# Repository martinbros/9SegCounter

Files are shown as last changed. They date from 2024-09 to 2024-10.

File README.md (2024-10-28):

# Nine Segment Counter SAO

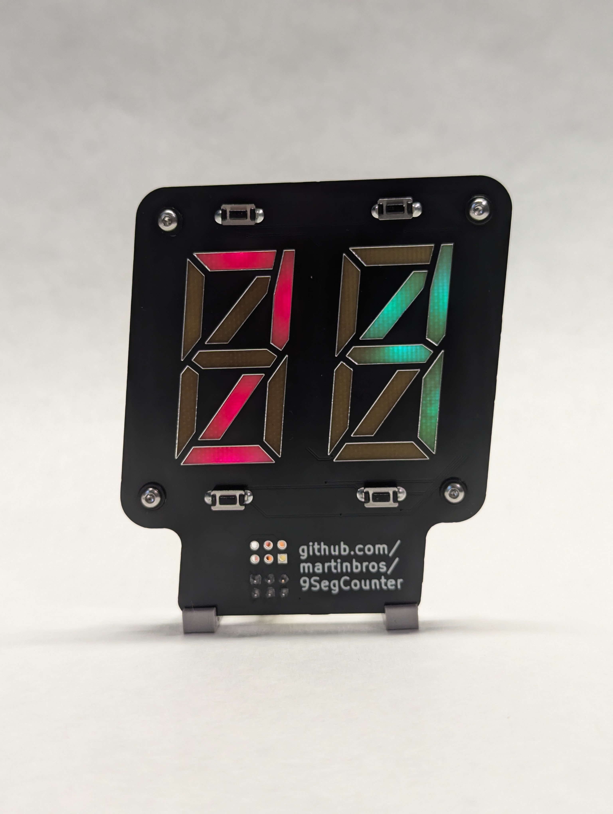
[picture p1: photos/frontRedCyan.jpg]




**Description**

Use this handy little SAO to count whatever your heart desires: how many conversations you have at Supercon, how many times someone asks what SAO stands for, how many times someone asks "What are you working on?".
By using the onboard buttons, I2C interface, or clocking the GP2 pin, the Nine Segment Counter SAO will indicate to the world whatever quantity you are keeping track of.

## Operation

Store a 2 digit number and display the number using an atypical 9 segment display instead of the typical 7

Using the buttons, a user can store 49 unique numbers in non-volatile memory. Each unique number is identified by the color of the digits.

Using the I2C bus, the user has full read and write access to the ATTiny 84's 512 byte EEPROM and has full command of the display (displayed number and digit color).

### Button Interface

- Pressing a button above a digit increases that digit by 1
- Pressing a button below a digit decreases that digit by 1
- The displayed digit is stored as a decimal 2 digit number (0-99)
- Pressing the buttons above and below a digit simultaneously changes the color of that digit
  - Each unique two digit color combination corresponds to a unique number saved in non-volatile memory
  - 7 unique colors per "ones" digit x 7 unique colors per "tens" digit = 49 unique values stored in non-volatile memory
  - EEPROM Address location is built by taking the "ones" position color index (0-6) and adding it to the "tens" position color index which has been multipled by 10 (0-6 x 10) [e.g. 00, 02, 03 ... 07, 10, 11 ... 17, 20 ... 27 ... 77]

### I2C Interface

- I2C Address: 4

**Display Functions**

- 1 8-bit message: the display will update to show the sent number (Displayed number is not stored in memory)
- 3 8-bit messages: set the RGB values of the digits to be displayed (Digit must be refreshed to update color)
- 6 8-bit messages: set the RGB values of the tens place digit and then ones place digit (Digit must be refreshed to update color)

**Memory Functions**

- 2 8-bit message: The sent number is converted to a 16-bit EEPROM address pointer, the display will update to display the value stored in memory.
- 4 8-bit messages: first 2 bytes are combined to a 16-bit EEPROM address pointer, third byte is the data to be stored in the EEPROM, the last byte is a throwaway
- 5 8-bit messages: The entire EEPROM is filled with the contents of the first message, the remaining 4 messages are discarded

### GP1 Interface

- GP1 is normally pulled high. By driving GP1 low, the displayed number will be incremented by 1
- Max clock speed is ~150Hz
- Displayed number is not stored in memory 

### GP2 Interface

- GP2 is connected directly to the first Neopixel and is terminated with a 470 ohm resistor. If you desire, feel free to implement the Neopixel protocol and set the segments however you like! Use the reference photo below for the sequence of the neopixels.

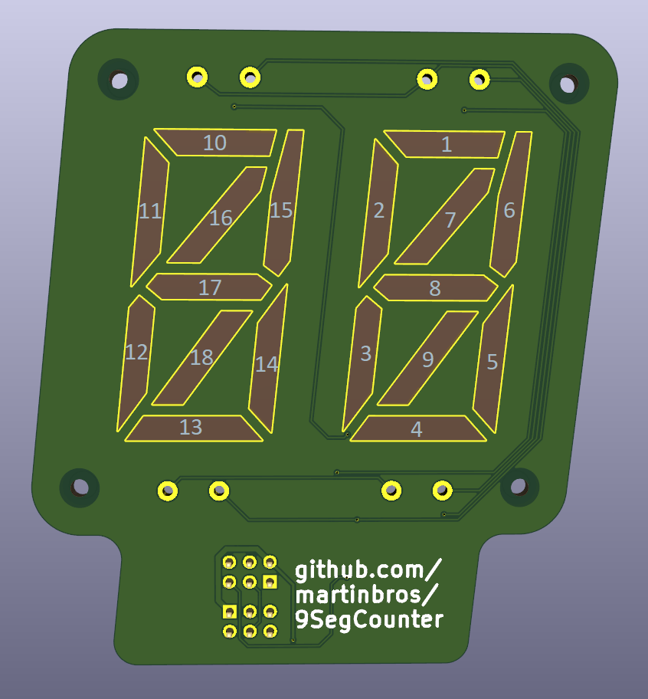
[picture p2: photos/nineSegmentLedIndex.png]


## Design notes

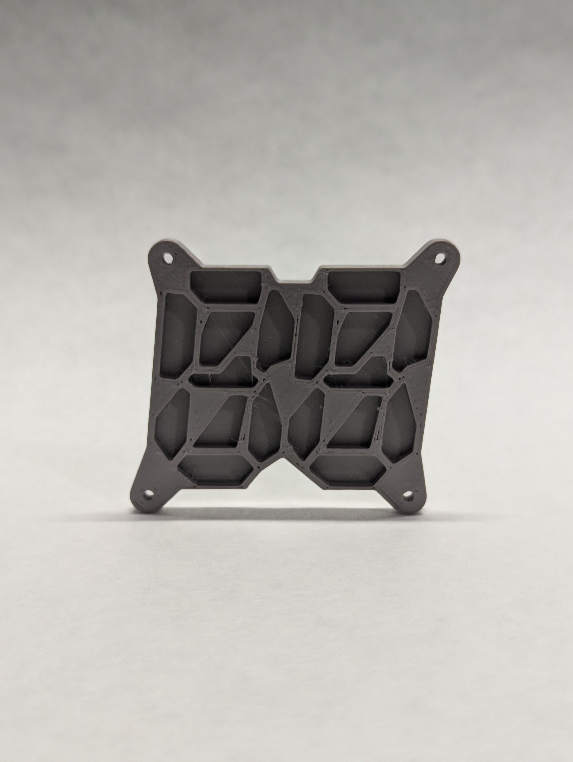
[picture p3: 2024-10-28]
photos/separator.jpg

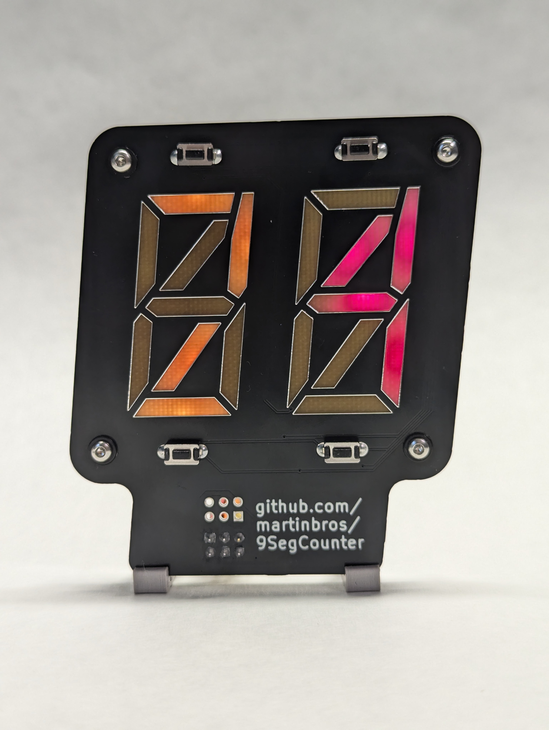
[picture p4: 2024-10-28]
photos/frontYellowRed.jpg

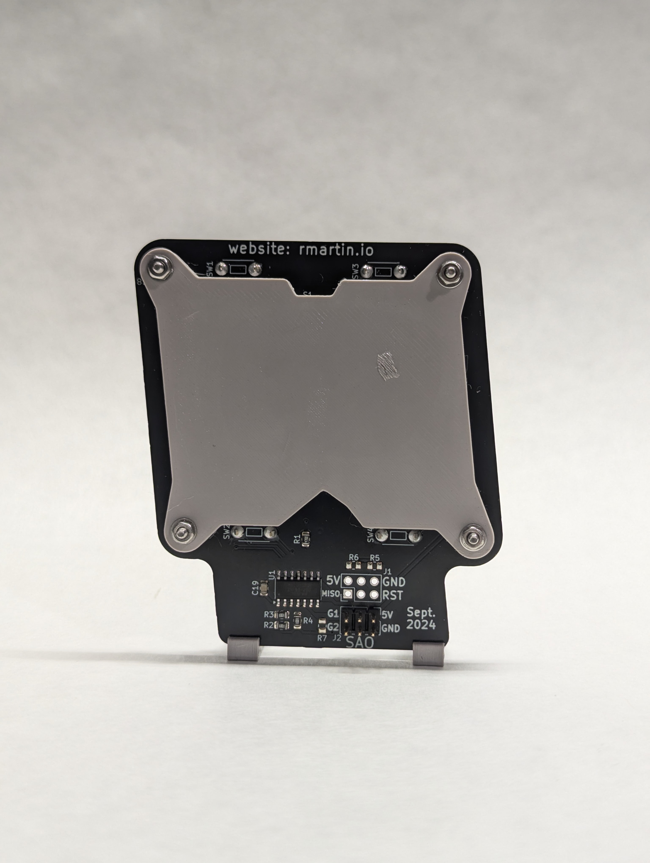
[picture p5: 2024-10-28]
photos/backSeparator.jpg

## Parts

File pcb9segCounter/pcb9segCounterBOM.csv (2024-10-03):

Reference | Value | Datasheet | Footprint | Qty | DNP | MFG | MPN
C1,C2,C3,C4,C5,C6,C7,C8,C9,C10,C11,C12,C13,C14,C15,C16,C17,C18,C19 | 0.1u | ~ | Capacitor_SMD:C_0805_2012Metric | 19 |  | Kemet | C0805C104K5RAC7210
D1,D2,D3,D4,D5,D6,D7,D8,D9,D10,D11,D12,D13,D14,D15,D16,D17,D18 | ~ | https://cdn-shop.adafruit.com/product-files/5849/SK6805-EC10-000_REV.01_EN.pdf | customParts:1x1mm SMD RGB LED | 18 |  | Dongguan | SK6805-EC10
J1 | AVR-ISP-6 | ~ | Connector_PinHeader_2.54mm:PinHeader_2x03_P2.54mm_Vertical | 1 |  | Amphenol FCI | 10129381-906002BLF
J2 | SAO | ~ | Connector_PinHeader_2.54mm:PinHeader_2x03_P2.54mm_Vertical | 1 |  | Amphenol FCI | 10129381-906002BLF
R1 | 500 | ~ | Resistor_SMD:R_0805_2012Metric | 1 |  | Yago | RC0805FR-07470RL
R2,R3,R5,R6,R7 | 1k | ~ | Resistor_SMD:R_0805_2012Metric | 5 |  | Yago | RC0805FR-071KL
R4 | 1k | ~ | Resistor_SMD:R_0805_2012Metric_Pad1.20x1.40mm_HandSolder | 1 |  | Yago | RC0805FR-071KL
S1,S2 | ~ |  | customParts:9 Segment 38x19x3 | 2 |  | na | na
SW1,SW2,SW3,SW4 | ~ | ~ | customParts:PTS636 SK43 LFS | 4 |  | C&K | PTS636 SK43 LFS
U1 | ATtiny84A-SS | http://ww1.microchip.com/downloads/en/DeviceDoc/doc8183.pdf | Package_SO:SOIC-14_3.9x8.7mm_P1.27mm | 1 |  | Microchip | ATTINY84-20SSU

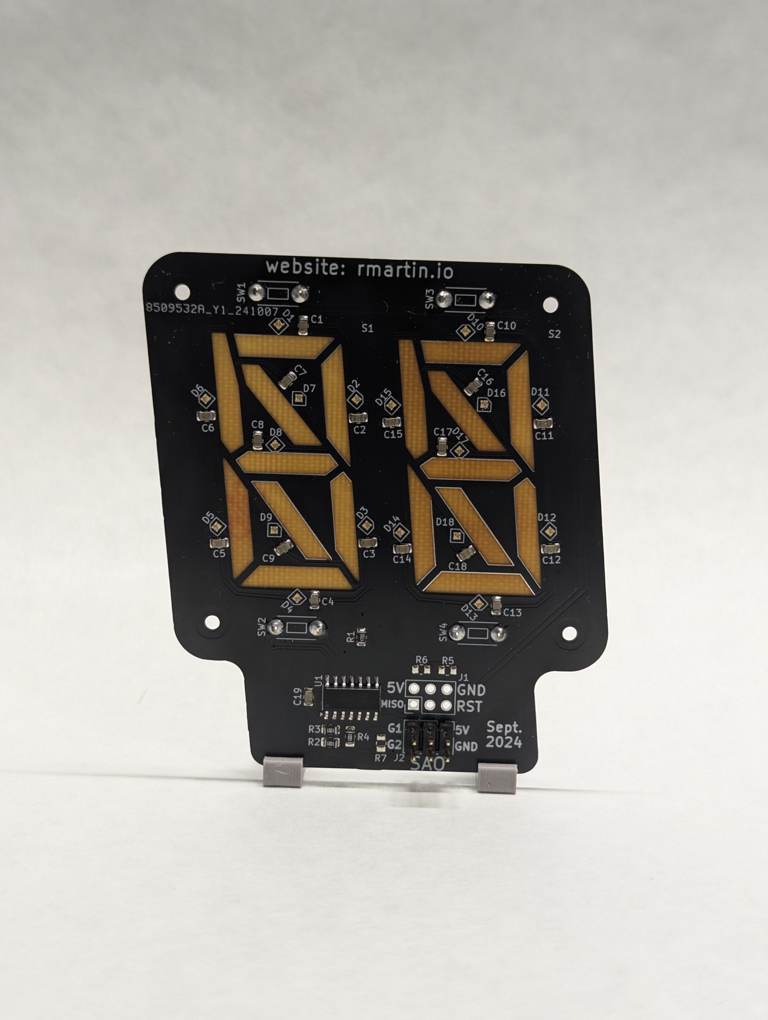
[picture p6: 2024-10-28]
photos/backComponents.jpg

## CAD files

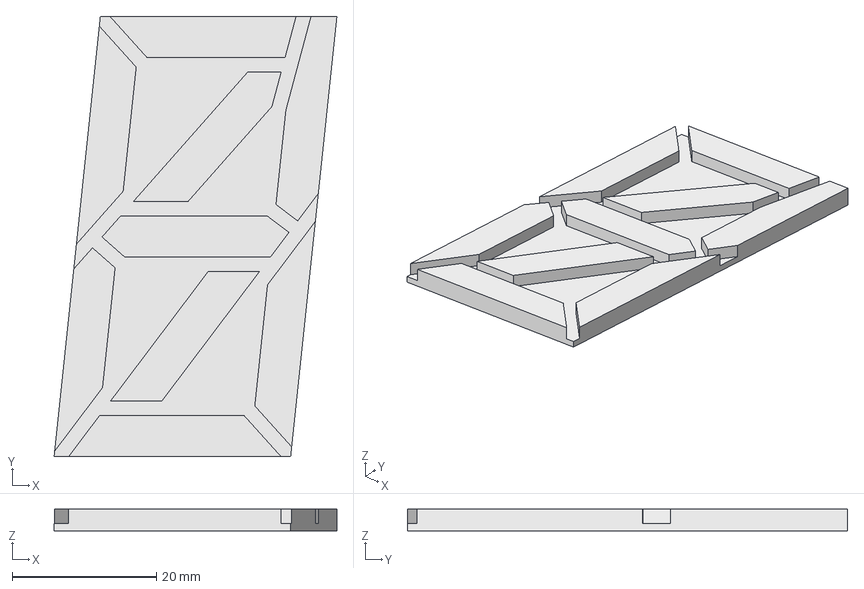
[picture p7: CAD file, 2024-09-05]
cad9segment/9SegmentV2.FCStd
39.2 x 61.0 x 3.00 mm

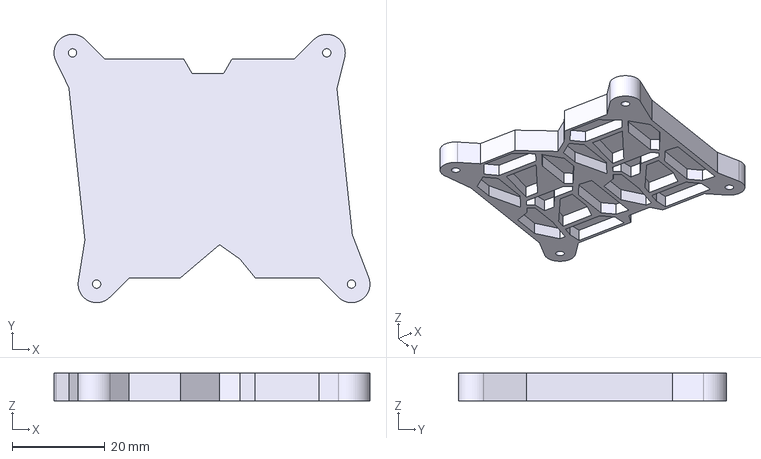
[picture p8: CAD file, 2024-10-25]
cadBackSeparator/saoBackSeparator-TaperedHoles.step
68.2 x 57.9 x 6.00 mm

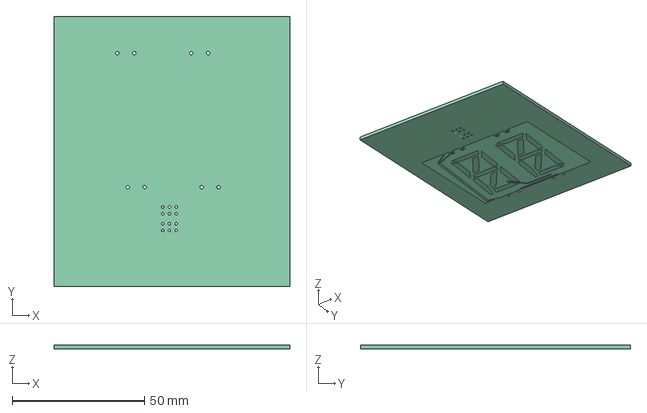
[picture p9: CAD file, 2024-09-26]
pcb9segCounter/3dModelOfBoard/3dBoard.FCStd
89.2 x 102.2 x 1.61 mm
Pcb_a7f9
botZones_a7f9

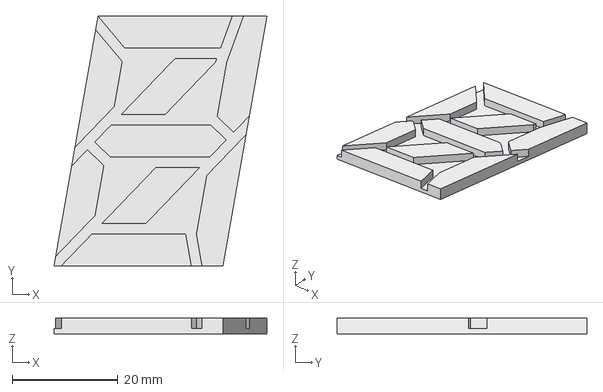
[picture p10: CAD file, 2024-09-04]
cad9segment/9segmentDisplay.FCStd
40.3 x 47.3 x 3.00 mm

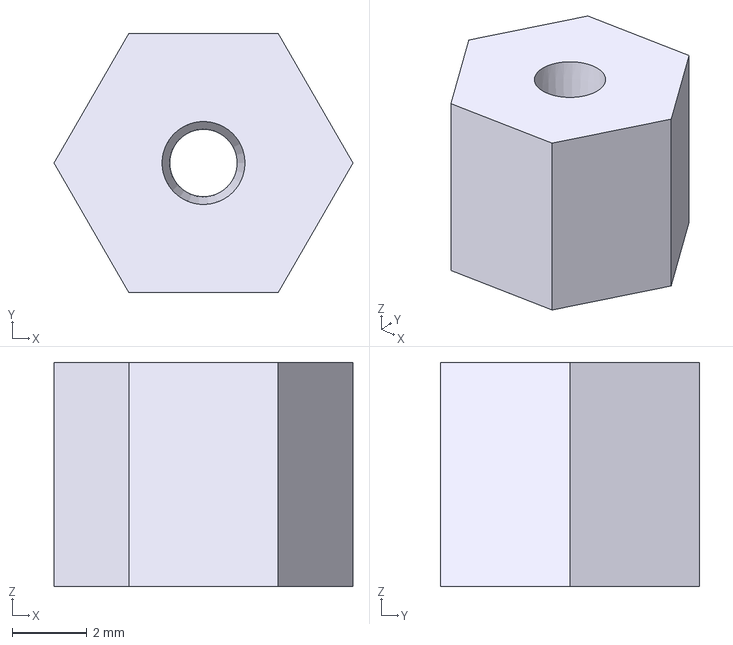
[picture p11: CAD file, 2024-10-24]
cadBackSeparator/saoBackSeparator.FCStd
8.00 x 6.93 x 6.00 mm

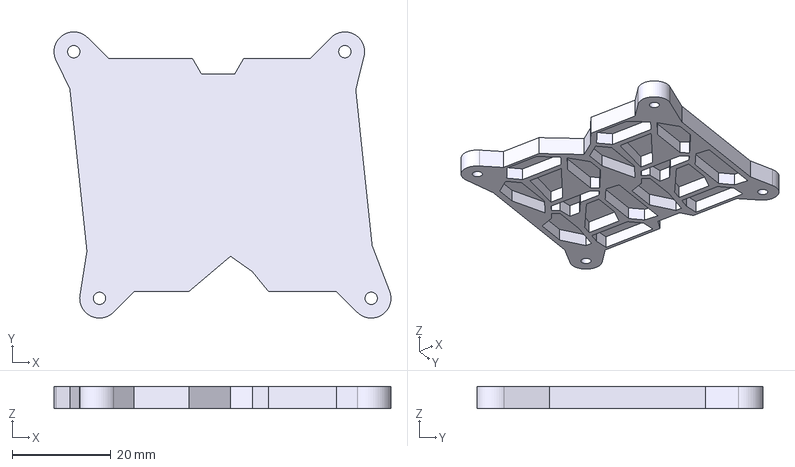
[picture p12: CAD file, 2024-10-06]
cadBackSeparator/saoBackSeparator-rightHoles.step
68.2 x 57.9 x 4.50 mm

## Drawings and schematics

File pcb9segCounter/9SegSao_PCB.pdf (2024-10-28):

1 | 2 | 3 | 4 | 5 | 6

A

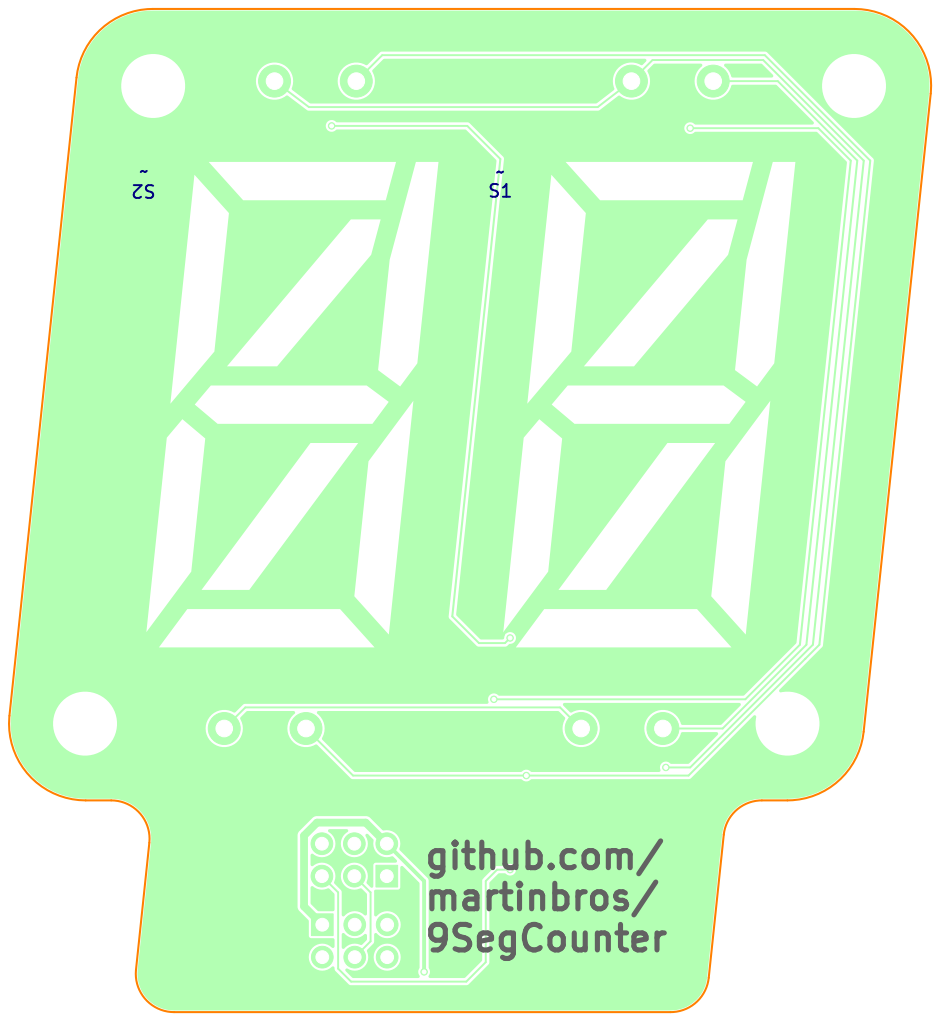
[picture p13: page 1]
github.com/ martinbros/ 9SegCounter; D Date: KiCad; E.D.A. 8.0.5 Size: A4; Rev:

Id: 1/1 Title: File: pcb9segCounter.kicad_pcb Sheet:

# Sept. 2024 website: rmartin.io

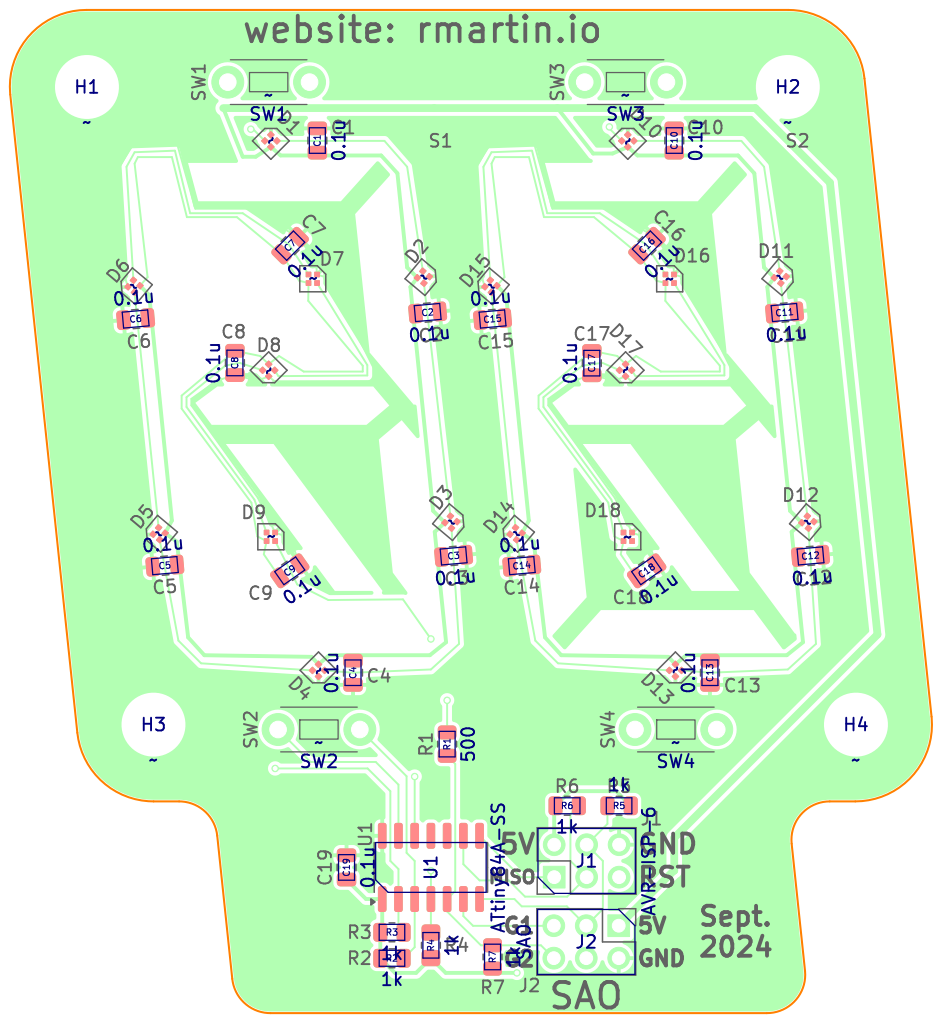
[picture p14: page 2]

# Sept. 2024 website: rmartin.io

A

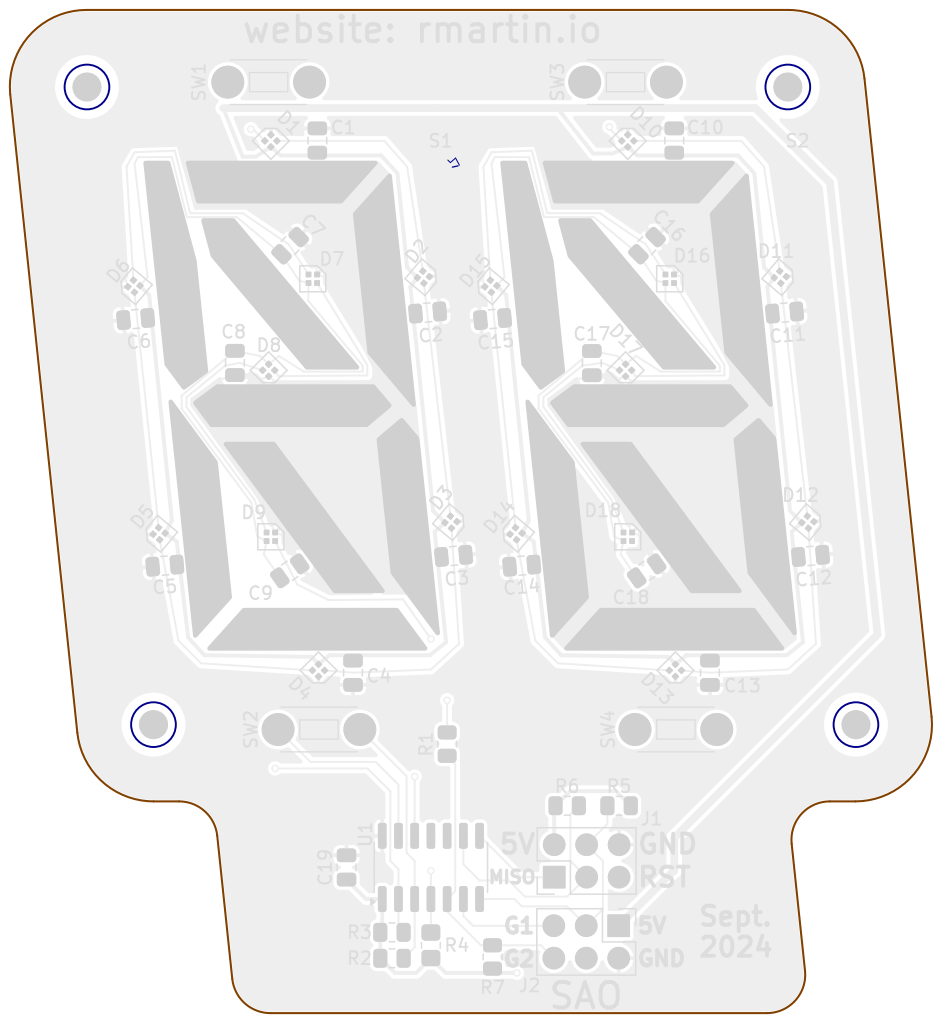
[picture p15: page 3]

Id: 1/1 Title: File: pcb9segCounter.kicad_pcb Sheet:

A

A

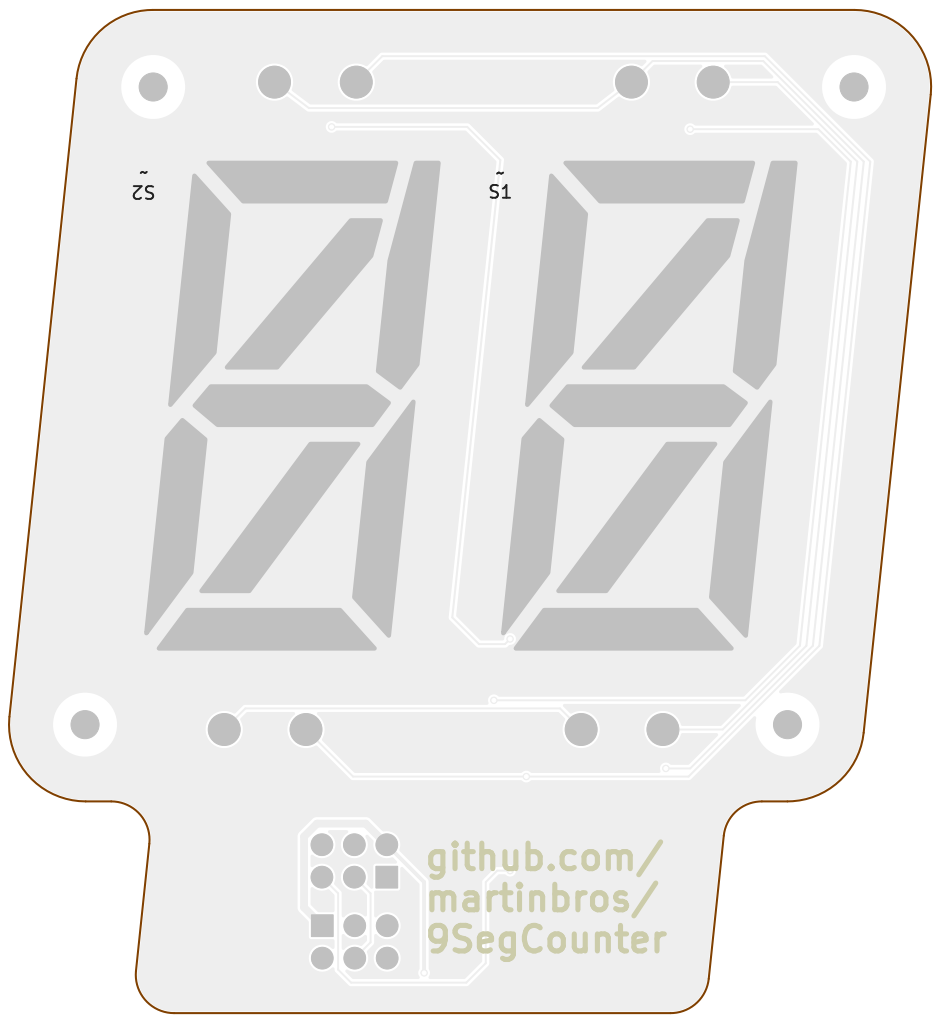
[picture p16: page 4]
github.com/ martinbros/ 9SegCounter; D Date: KiCad; E.D.A. 8.0.5 Size: A4; Rev:

Id: 1/1 Title: File: pcb9segCounter.kicad_pcb Sheet:

# Sept. 2024 website: rmartin.io

R3 0.1u | C⁴ ~H1 | 0.1u C¹⁹ | 1kR⁷ ~ | ~ ATtiny84A⁻SS U¹ | 500R¹ | ~H4 ⁰.1uC¹ ~ SW1 | 1kR⁴ ~ | 0.1u | C¹⁷ 1 | 2 | 3 | 4 | 5 | 6 1 | 2 | 3 | 4 | 5 | 6 ABCD | ABCD Date: KiCad | E.D.A. 8.0.5 Size: A4 | Rev:

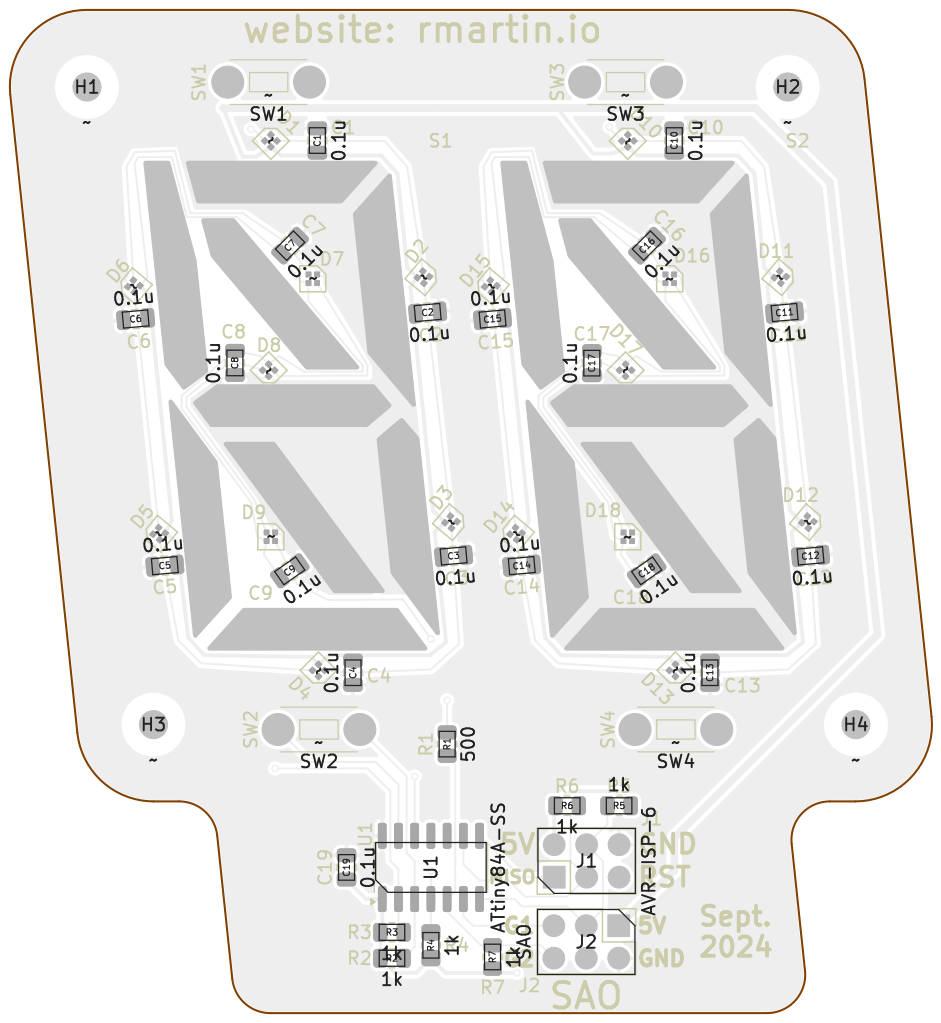
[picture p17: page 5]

Id: 1/1 Title: File: pcb9segCounter.kicad_pcb Sheet:

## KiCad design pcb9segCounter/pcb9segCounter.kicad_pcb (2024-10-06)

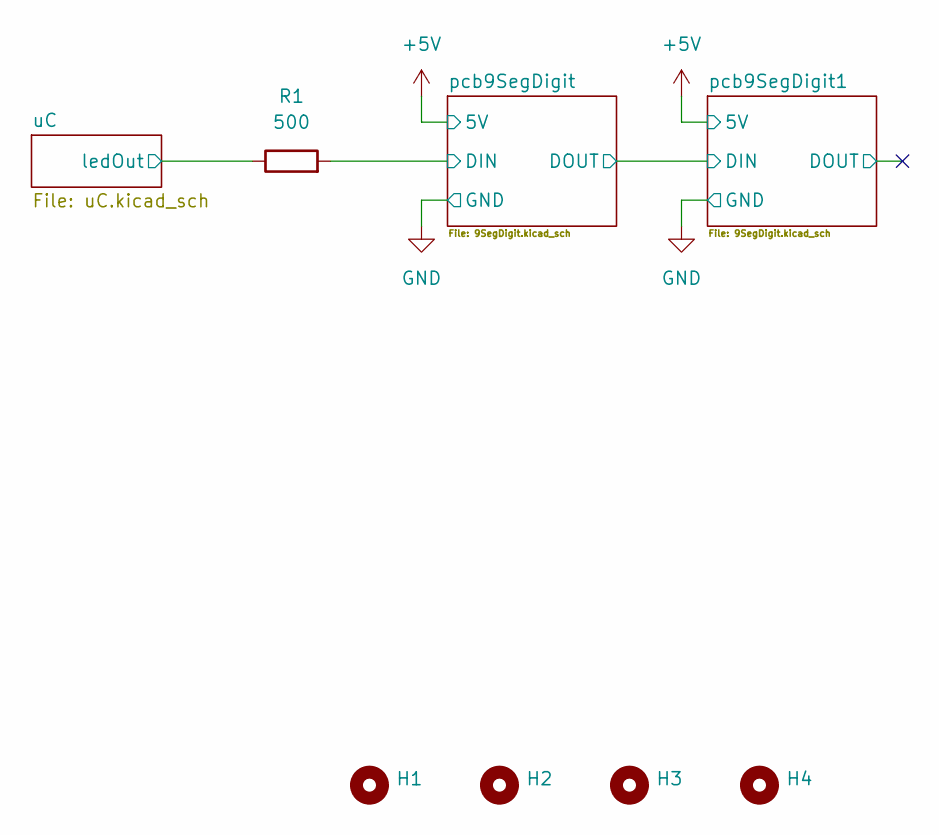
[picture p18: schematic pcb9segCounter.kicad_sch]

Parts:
H1, H2, H3, H4: MountingHole_2.2mm_M2_ISO7380
R1: 500; R_0805_2012Metric

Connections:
/pcb9SegDigit/DIN: R1.2; also elsewhere on the board
GP2: R1.1; also elsewhere on the board

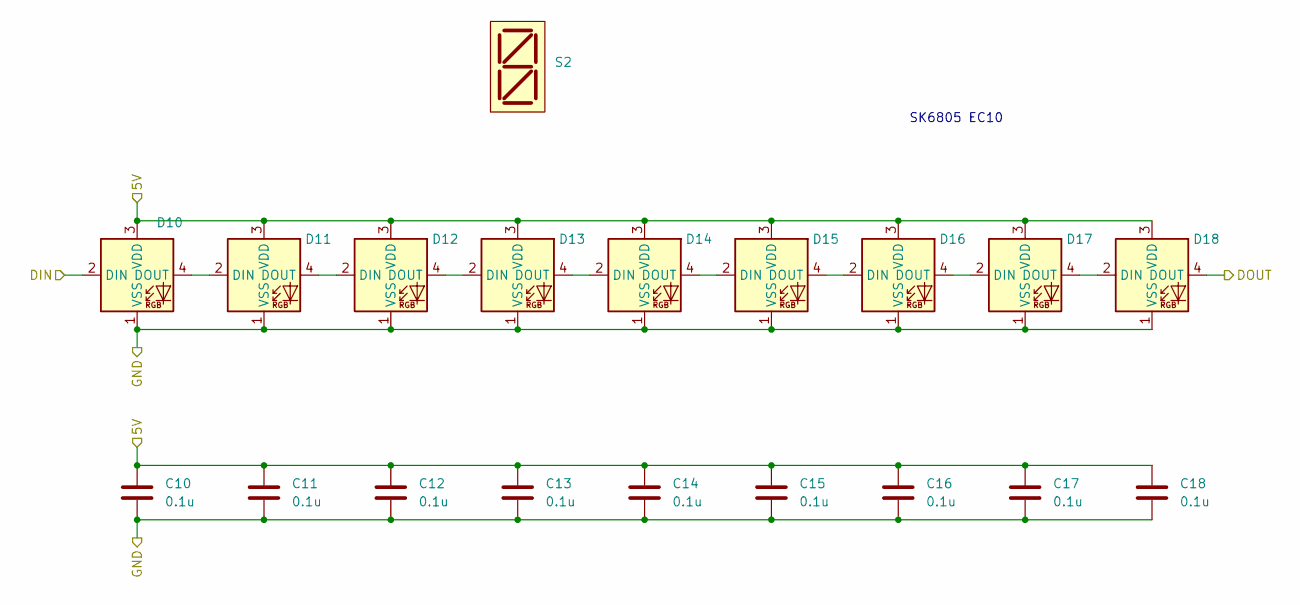
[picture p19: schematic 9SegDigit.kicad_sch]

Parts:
C10, C11, C12, C13, C14, C15, C16, C17, C18: 0.1u; C_0805_2012Metric
D10, D11, D12, D13, D14, D15, D16, D17, D18: 1x1mm SMD RGB LED; MPN SK6805-EC10
S2: 9 Segment 38x19x3

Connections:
+5V: C10.1, C11.1, C12.1, C13.1, C14.1, C15.1, C16.1, C17.1, C18.1, D10.3 (VDD), D11.3 (VDD), D12.3 (VDD), D13.3 (VDD), D14.3 (VDD), D15.3 (VDD), D16.3 (VDD), D17.3 (VDD), D18.3 (VDD); also elsewhere on the board
/pcb9SegDigit1/DOUT: D18.4 (DOUT)
/pcb9SegDigit/DOUT: D10.2 (DIN); also elsewhere on the board
GND: C10.2, C11.2, C12.2, C13.2, C14.2, C15.2, C16.2, C17.2, C18.2, D10.1 (VSS), D11.1 (VSS), D12.1 (VSS), D13.1 (VSS), D14.1 (VSS), D15.1 (VSS), D16.1 (VSS), D17.1 (VSS), D18.1 (VSS); also elsewhere on the board
unnamed: D10.4 (DOUT), D11.2 (DIN)
unnamed: D11.4 (DOUT), D12.2 (DIN)
unnamed: D12.4 (DOUT), D13.2 (DIN)
unnamed: D13.4 (DOUT), D14.2 (DIN)
unnamed: D14.4 (DOUT), D15.2 (DIN)
unnamed: D15.4 (DOUT), D16.2 (DIN)
unnamed: D16.4 (DOUT), D17.2 (DIN)
unnamed: D17.4 (DOUT), D18.2 (DIN)

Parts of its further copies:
C1, C2, C3, C4, C5, C6, C7, C8, C9: 0.1u; C_0805_2012Metric
D1, D2, D3, D4, D5, D6, D7, D8, D9: 1x1mm SMD RGB LED; MPN SK6805-EC10
S1: 9 Segment 38x19x3

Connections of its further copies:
+5V: C1.1, C2.1, C3.1, C4.1, C5.1, C6.1, C7.1, C8.1, C9.1, D1.3 (VDD), D2.3 (VDD), D3.3 (VDD), D4.3 (VDD), D5.3 (VDD), D6.3 (VDD), D7.3 (VDD), D8.3 (VDD), D9.3 (VDD); also elsewhere on the board
/pcb9SegDigit/DIN: D1.2 (DIN); also elsewhere on the board
/pcb9SegDigit/DOUT: D9.4 (DOUT); also elsewhere on the board
GND: C1.2, C2.2, C3.2, C4.2, C5.2, C6.2, C7.2, C8.2, C9.2, D1.1 (VSS), D2.1 (VSS), D3.1 (VSS), D4.1 (VSS), D5.1 (VSS), D6.1 (VSS), D7.1 (VSS), D8.1 (VSS), D9.1 (VSS); also elsewhere on the board
unnamed: D1.4 (DOUT), D2.2 (DIN)
unnamed: D2.4 (DOUT), D3.2 (DIN)
unnamed: D3.4 (DOUT), D4.2 (DIN)
unnamed: D4.4 (DOUT), D5.2 (DIN)
unnamed: D5.4 (DOUT), D6.2 (DIN)
unnamed: D6.4 (DOUT), D7.2 (DIN)
unnamed: D7.4 (DOUT), D8.2 (DIN)
unnamed: D8.4 (DOUT), D9.2 (DIN)

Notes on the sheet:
SK6805 EC10

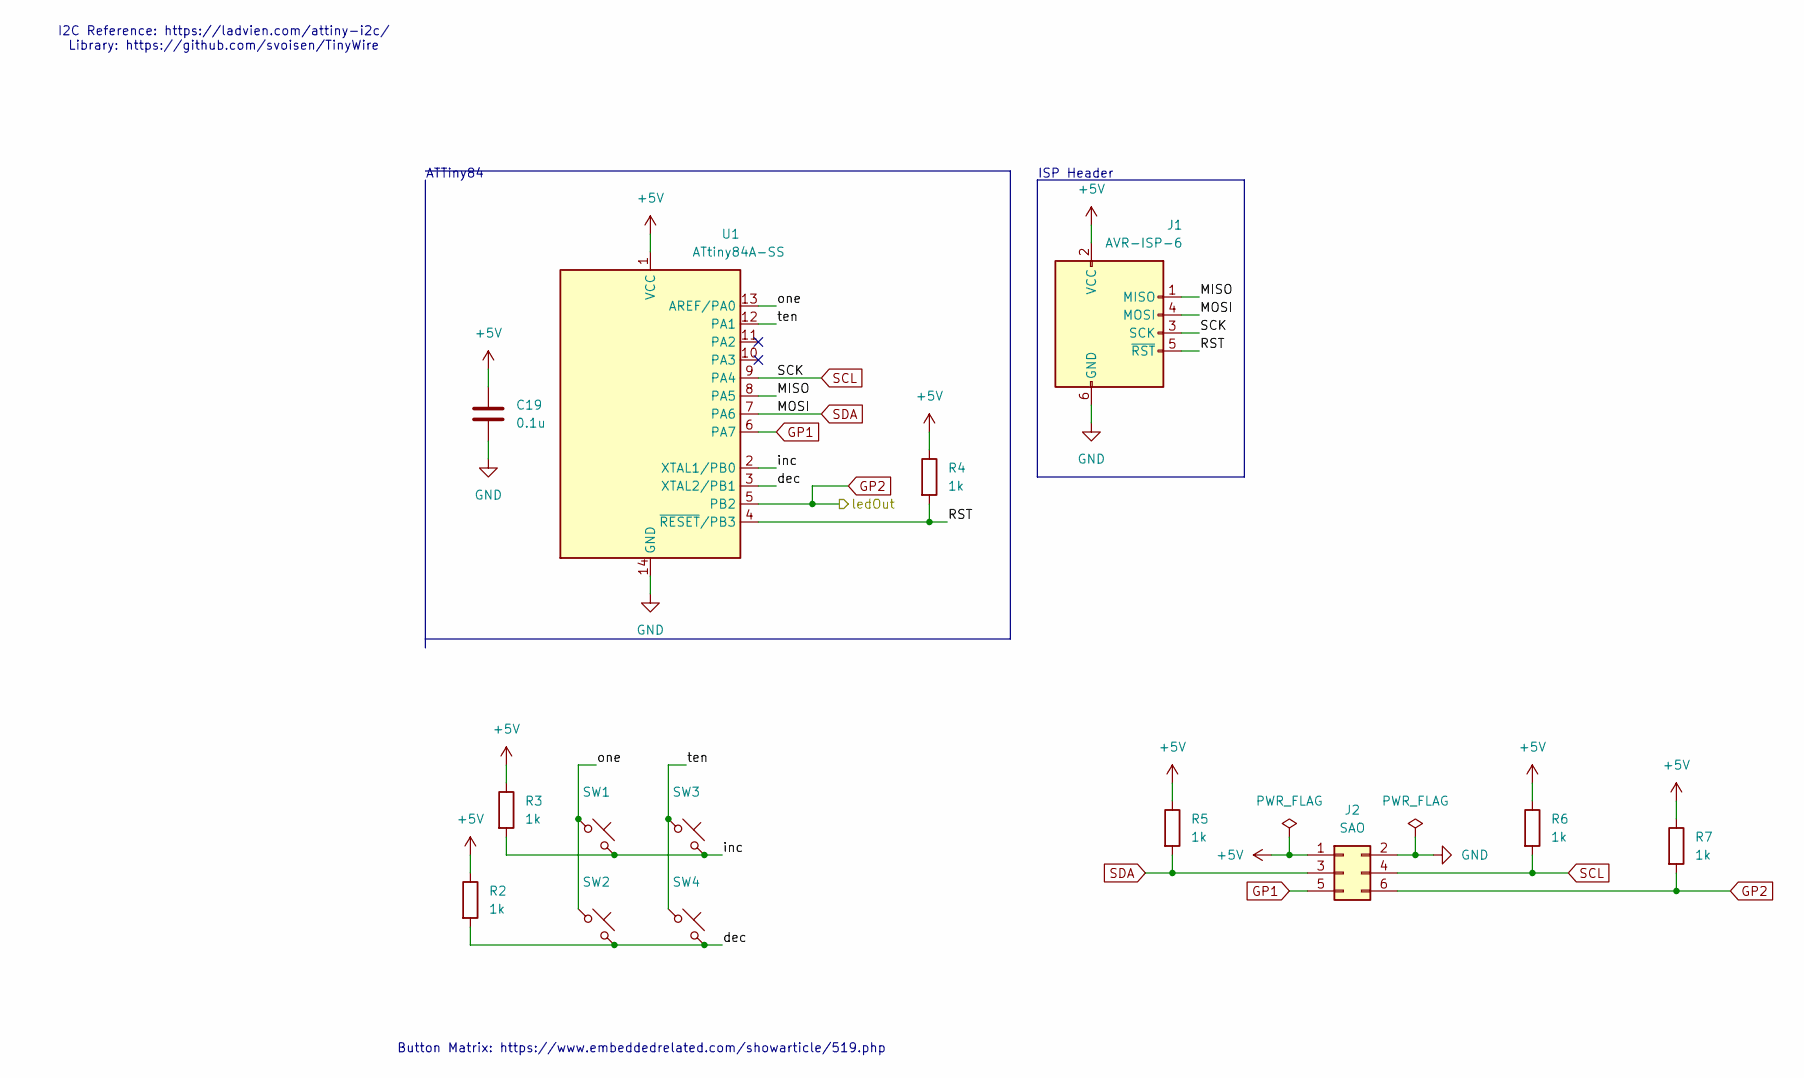
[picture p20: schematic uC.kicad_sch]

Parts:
C19: 0.1u; C_0805_2012Metric; mouserPN 80-C0805C104M3R
J1: AVR-ISP-6; PinHeader_2x03_P2.54mm_Vertical; MPN 10129381-906002BLF
J2: SAO; PinHeader_2x03_P2.54mm_Vertical; MPN 10129381-906002BLF
R2, R3, R5, R6, R7: 1k; R_0805_2012Metric
R4: 1k; R_0805_2012Metric_Pad1.20x1.40mm_HandSolder; mouserPN 71-CRCW08051K00JNEAC
SW1, SW2, SW3, SW4: PTS636 SK43 LFS; MPN PTS636 SK43 LFS
U1: ATtiny84A-SS; SOIC-14_3.9x8.7mm_P1.27mm; mouserPN 556-ATTINY84-20SSU

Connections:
+5V: C19.1, J1.2 (VCC), J2.1, R2.1, R3.1, R4.1, R5.1, R6.1, R7.1, U1.1 (VCC); also elsewhere on the board
/uC/MISO: J1.1 (MISO), U1.8 (PA5)
/uC/RST: J1.5 (~RST), R4.2, U1.4 (~RESET/PB3)
/uC/dec: R2.2, SW2.2, SW4.2, U1.3 (XTAL2/PB1)
/uC/inc: R3.2, SW1.2, SW3.2, U1.2 (XTAL1/PB0)
/uC/one: SW1.1, SW2.1, U1.13 (AREF/PA0)
/uC/ten: SW3.1, SW4.1, U1.12 (PA1)
GND: C19.2, J1.6 (GND), J2.2, U1.14 (GND); also elsewhere on the board
GP1: J2.5, U1.6 (PA7)
GP2: J2.6, R7.2, U1.5 (PB2); also elsewhere on the board
SCL: J1.3 (SCK), J2.4, R6.2, U1.9 (PA4)
SDA: J1.4 (MOSI), J2.3, R5.2, U1.7 (PA6)

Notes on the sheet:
ATTiny84
ISP Header
I2C Reference: https://ladvien.com/attiny-i2c/ Library: https://github.com/svoisen/TinyWire
Button Matrix: https://www.embeddedrelated.com/showarticle/519.php

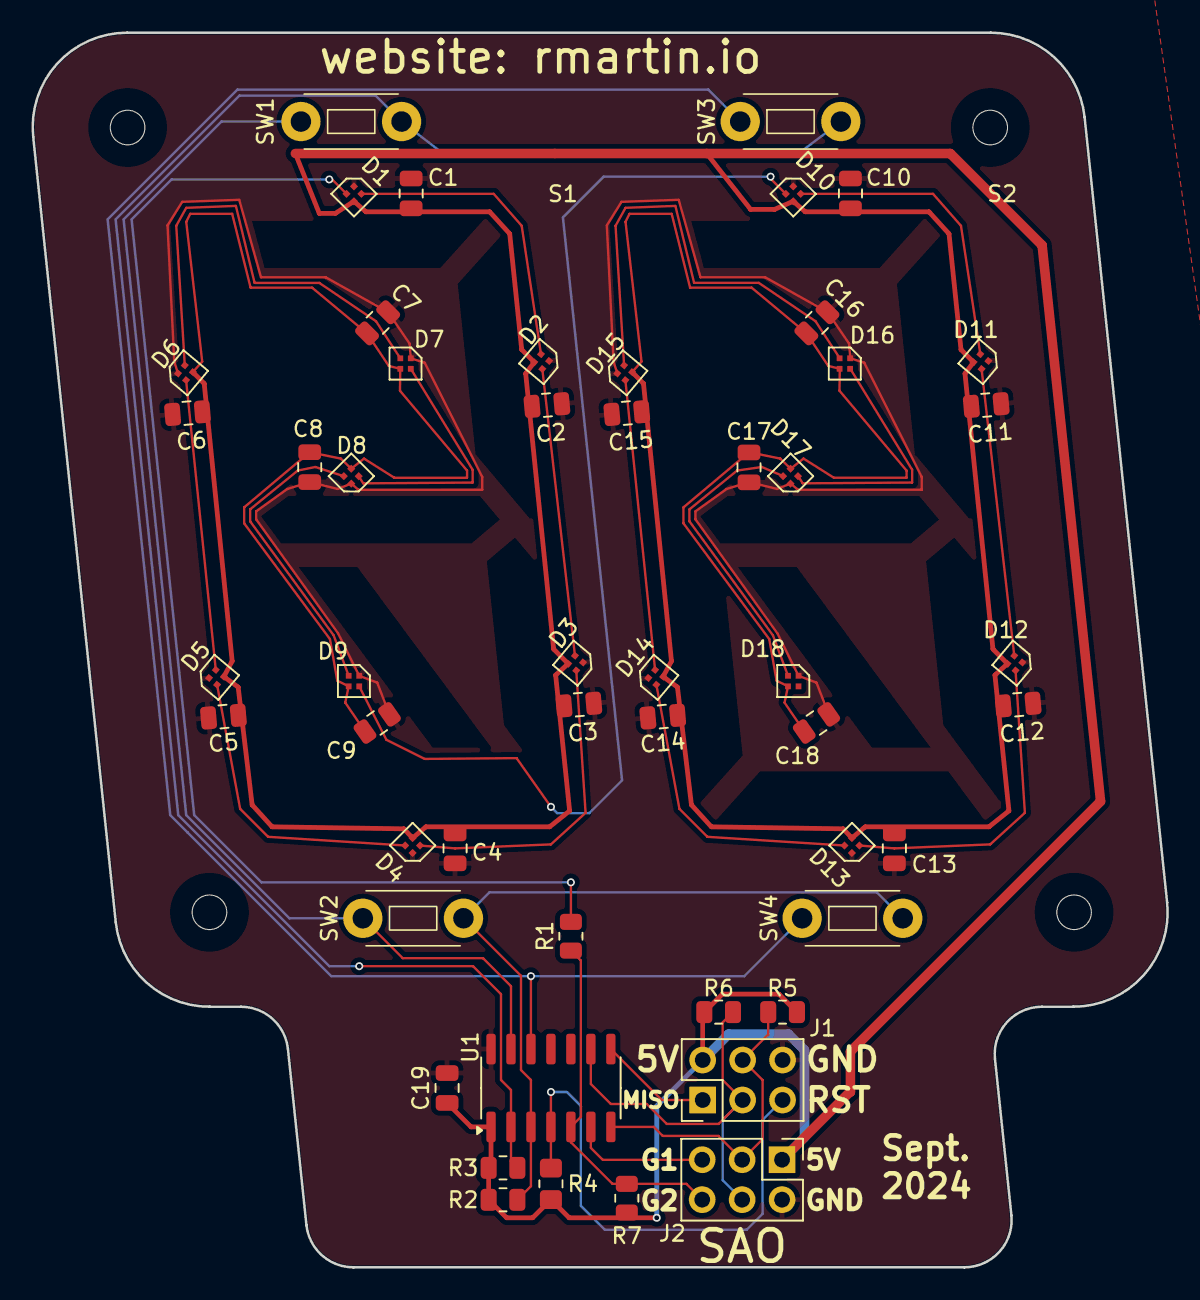
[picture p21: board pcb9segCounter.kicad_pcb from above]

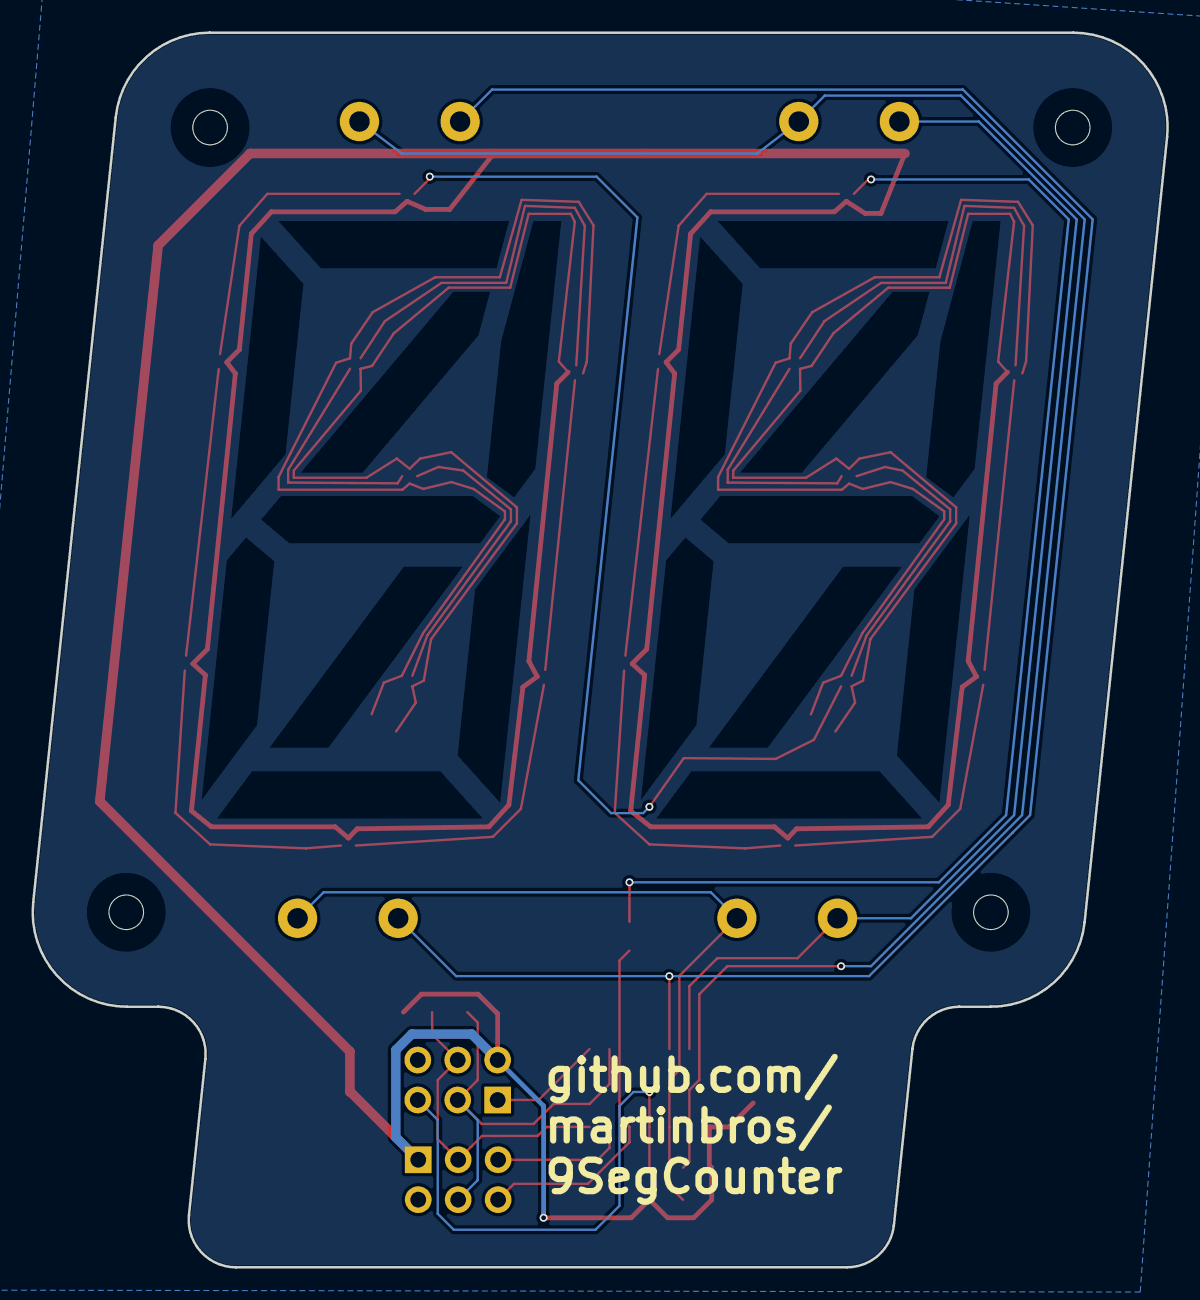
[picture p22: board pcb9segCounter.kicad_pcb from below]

Board: 2 copper layers, 72.2 x 78.5 mm, 57 parts (2 on the bottom side), 30 nets.

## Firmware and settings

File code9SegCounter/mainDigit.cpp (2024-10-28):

#include <avr/io.h>
#include <avr/interrupt.h>
#include <avr/eeprom.h>
#include <util/delay.h>

extern "C"
{
	#include "NineSegSao.h"
}

#define I2C_SLAVE_ADDRESS 0x4 // the 7-bit address (remember to change this when adapting this example)
// Get this from https://github.com/rambo/TinyWire
#include "TinyWireS.h"
// The default buffer size, Can't recall the scope of defines right now
#ifndef TWI_RX_BUFFER_SIZE
#define TWI_RX_BUFFER_SIZE ( 16 )
#endif

#define redScale 0xFF
#define greenScale 0xFF
#define blueScale 0xFF
uint8_t colors[][3] = {{0x00, 0x00, blueScale},
						{0x00, greenScale, 0x00},
						{0x00, greenScale, blueScale},
						{redScale, 0x00, 0x00},
						{redScale, 0x00, blueScale},
						{redScale, greenScale, 0x00},
						{redScale, greenScale, blueScale}};

volatile uint8_t display = 0x00;
volatile uint8_t update = 0x02;
uint8_t *address;

volatile uint8_t i2c_regs[] =
{
    0x01, 
    0x02, 
    0x03, 
    0x04,
    0x05,
    0x06 
};
const uint8_t reg_size=sizeof(i2c_regs);
volatile uint8_t reg_position;
volatile uint8_t sentSize = 0x00;

void disableLedPin()
{
	DDRB = 0x00;
	PORTB &= ~(0x04);
}

void enableLedPin()
{
	DDRB |= 0x04;
}

void receiveEvent(uint8_t howMany)
{
    if (howMany < 1)
    {
        // Sanity-check
        return;
    }
    if (howMany > TWI_RX_BUFFER_SIZE)
    {
        // Also insane number
        return;
    }

    reg_position = 0x00;
    sentSize = howMany;
    while(howMany--)
    {
        i2c_regs[reg_position] = TinyWireS.receive();
        reg_position++;
        if (reg_position >= reg_size)
        {
            reg_position = 0;
        }
    }

    update = 0x03;
}

void requestEvent()
{  
    TinyWireS.send(eeprom_read_byte(address));
}

ISR(PCINT0_vect){ // Interrupt for the clock pin
	
	if (!(PINA & (1<<PINA7))) // if PINA7 is low
	{
		display ++;
		display %= 100;
		update = 0x04;
	}
	
	//display ++;
	//update = 0x04;
}

int main(void)
{
	initializeIO();

	TinyWireS.begin(I2C_SLAVE_ADDRESS);
    TinyWireS.onReceive(receiveEvent);
    TinyWireS.onRequest(requestEvent);

	sei(); /* enable interrupts */

	uint8_t button = 0x00;
	
	uint16_t oneColorIdx = 0x00;
	uint16_t tenColorIdx = 0x00;
	
	uint8_t oneRedColor = colors[oneColorIdx][0];
	uint8_t oneGrnColor = colors[oneColorIdx][1];
	uint8_t oneBluColor = colors[oneColorIdx][2];
	uint8_t tenRedColor = colors[oneColorIdx][0];
	uint8_t tenGrnColor = colors[oneColorIdx][1];
	uint8_t tenBluColor = colors[oneColorIdx][2];

	//uint8_t *address;
	address = (uint8_t *) (tenColorIdx * 10 + oneColorIdx);


	while (1)
	{
		button = filter_keypad_original();  // Get button press status

		switch (button)
		{
			case 0x01: // ones place increase
				display += 1;
				update = 0x01;
				break;

			case 0x02: // ones place decrease

				if (display != 0)
					display -= 1;
				else
					display = 0;
				update = 0x01;
				break;

			case 0x03: // ones place both button press
				oneColorIdx += 1;
				oneColorIdx %= 7;

				oneRedColor = colors[oneColorIdx][0];
				oneGrnColor = colors[oneColorIdx][1];
				oneBluColor = colors[oneColorIdx][2];

				address = (uint8_t *) (tenColorIdx * 10 + oneColorIdx);
				
				update = 0x02;
				break;

			case 0x04: // tens place increase
				display += 10;
				update = 0x01;
				break;

			case 0x08: // tens place decrease
				if (display > 10)
					display -= 10;
				else
					display = 0;
				update = 0x01;
				break;

			case 0x0c: // tens place both button press
				tenColorIdx += 1;
				tenColorIdx %= 7;

				tenRedColor = colors[tenColorIdx][0];
				tenGrnColor = colors[tenColorIdx][1];
				tenBluColor = colors[tenColorIdx][2];

				address = (uint8_t *) (tenColorIdx * 10 + oneColorIdx);

				update = 0x02;
				break;
		}

		switch(sentSize)
		{
			case 0x01:  // One byte via I2C

				display = i2c_regs[0];  // Update Display
				sentSize = 0x00;
				break;
			
			case 0x02:  // Two bytes via I2C
				address = (uint8_t *) ((i2c_regs[0] << 8) | i2c_regs[1]);  // Update address from message
				sentSize = 0x00;
				update = 0x02;  // Update Display from data at address
				break;
			
			case 0x03:  // Three bytes via I2C
				// Set Digits color
				oneRedColor = i2c_regs[0];
				oneGrnColor = i2c_regs[1];
				oneBluColor = i2c_regs[2];

				tenRedColor = i2c_regs[0];
				tenGrnColor = i2c_regs[1];
				tenBluColor = i2c_regs[2];

				sentSize = 0x00;
				update = 0x00;  // Do not update display
				break;
			
			case 0x04: // Four bytes via I2C
				address = (uint8_t *) ((i2c_regs[0] << 8) | i2c_regs[1]); // Update address from message
				eeprom_write_byte(address, i2c_regs[2]); // Write third byte to EEPROM
				
				sentSize = 0x00;
				update = 0x00;  // Do not update display
				break;

			case 0x05:
				
				for (uint16_t idx = 0; idx < 512; idx++) 
				{
					uint8_t *adr;
					adr = (uint8_t *) idx;
					eeprom_write_byte(adr, i2c_regs[0]);
				}

				sentSize = 0x00;
				update = 0x03;
				break;
			
			case 0x06:  // Six bytes via I2C
				// Set Digits color
				tenRedColor = i2c_regs[0];
				tenGrnColor = i2c_regs[1];
				tenBluColor = i2c_regs[2];

				oneRedColor = i2c_regs[3];
				oneGrnColor = i2c_regs[4];
				oneBluColor = i2c_regs[5];

				sentSize = 0x00;
				update = 0x00; // Do not update display
				break;
		}

		if (display >= 100)
			display %= 100;
		

		if (update)  // update either number or address
		{
			enableLedPin();
			if (update == 0x01) // Write number to EEPROM
				eeprom_write_byte(address, display);
			if (update == 0x02) // Pull number from EEPROM
				display = eeprom_read_byte(address);

			set_digit(display % 10, 0, oneRedColor, oneGrnColor, oneBluColor);  // Set ones place number
			set_digit(display / 10 % 10, 1, tenRedColor, tenGrnColor, tenBluColor);  //Set tens place number
			write_pixels();
			write_pixels();
			update = 0x00;  // do not enter update
			disableLedPin();
		}

		TinyWireS_stop_check();
	}
}

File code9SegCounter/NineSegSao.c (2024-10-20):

#include <avr/io.h>
#include <util/delay.h>
#include <avr/interrupt.h>

#define F_CPU 8000000UL

#define PIXELS 18
#define PIXEL_PORT PORTB
#define PIXEL_DDR  DDRB
#define PIXEL_BIT  PORTB2
#define SCALE(val) ((val) >> 2)
static uint8_t grb[PIXELS*3];

#define KP_ROW_PORT   PORTA
#define KP_ROW_DDR    DDRA
#define KP_COL_PORT   PORTB
#define KP_COL_DDR    DDRB
#define KP_COL_PIN    PINB
#define KP_ROWS       2
#define KP_COLS       2
#define KP_FIRST_ROW  0
#define KP_FIRST_COL  0
#define KP_ROW_MASK   0b00000011
#define KP_COL_MASK   0b00000011

void set_pixel(uint8_t i, uint8_t r, uint8_t g, uint8_t b)
{
  uint8_t offset = (i % PIXELS) * 3;
  grb[offset] = SCALE(g);
  grb[offset+1] = SCALE(r);
  grb[offset+2] = SCALE(b);
}

void write_pixels(void) 
{
  cli(); /* disable interrupts */
  asm volatile(
      "1:"                    "\n\t" /* outer loop: iterate bytes */
      "ld %[byte], %a[grb]+"  "\n\t"
      "ldi %[bits], 8"        "\n\t"
      "2:"                    "\n\t" /* inner loop: write a byte */
      "sbi %[port], %[pin]"   "\n\t" /* t = 0 */
      "sbrs %[byte], 7"       "\n\t" /* 2c if skip, 1c if no skip */
      "cbi %[port], %[pin]"   "\n\t" /* 2c, t1 = 375ns */
      "lsl %[byte]"           "\n\t" /* 1c, t = 500 (0) / 375 (1) */
      "dec %[bits]"           "\n\t" /* 1c, t = 625 (0) / 500 (1) */
      "nop"                   "\n\t" /* 1c, t = 750 (0) / 625 (1) */
      "cbi %[port], %[pin]"   "\n\t" /* 2c, t2= 875 (0) / 750 (1) */
      "brne 2b"               "\n\t" /* 2c if skip, 1c if not */
      "dec %[nbytes]"         "\n\t"
      "brne 1b"               "\n\t"
      :: [nbytes]  "d" (PIXELS * 3)  /* how many pixels to write */
      ,  [grb]     "w" (grb)         /* pointer to grb byte array */
      ,  [byte]    "d" (16)
      ,  [bits]    "d" (17)
      ,  [port]    "i" (_SFR_IO_ADDR(PIXEL_PORT))
      ,  [pin]     "i" (PIXEL_BIT)
      );
  _delay_us(10);
  sei(); /* enable interrupts */
}

void clear_pixels(void)
{
	for (uint8_t idx = 0x00; idx < PIXELS*3; idx++) 
	{
		//grb[idx] = SCALE(0x00);
		grb[idx] = 0x00;
	}
		
	write_pixels();
	_delay_ms(10);
}

void set_digit(uint8_t digit, uint8_t pos, uint8_t r, uint8_t g, uint8_t b)
{
	pos = pos * 0x09;
	switch (digit)
	{
		case 0x00:
			set_pixel(pos + 0x00, r, g, b);
			set_pixel(pos + 0x01, r, g, b);
			set_pixel(pos + 0x02, r, g, b);
			set_pixel(pos + 0x03, r, g, b);
			set_pixel(pos + 0x04, r, g, b);
			set_pixel(pos + 0x05, r, g, b);
			set_pixel(pos + 0x06, 0x00, 0x00, 0x00);
			set_pixel(pos + 0x07, 0x00, 0x00, 0x00);
			set_pixel(pos + 0x08, 0x00, 0x00, 0x00);
			break;
		
		case 0x01:
			set_pixel(pos + 0x00, 0x00, 0x00, 0x00);
			set_pixel(pos + 0x01, 0x00, 0x00, 0x00);
			set_pixel(pos + 0x02, 0x00, 0x00, 0x00);
			set_pixel(pos + 0x03, 0x00, 0x00, 0x00);
			set_pixel(pos + 0x04, r, g, b);
			set_pixel(pos + 0x05, r, g, b);
			set_pixel(pos + 0x06, 0x00, 0x00, 0x00);
			set_pixel(pos + 0x07, 0x00, 0x00, 0x00);
			set_pixel(pos + 0x08, 0x00, 0x00, 0x00);
			break;
		
		case 0x02:
			set_pixel(pos + 0x00, r, g, b);
			set_pixel(pos + 0x01, 0x00, 0x00, 0x00);
			set_pixel(pos + 0x02, 0x00, 0x00, 0x00);
			set_pixel(pos + 0x03, r, g, b);
			set_pixel(pos + 0x04, 0x00, 0x00, 0x00);
			set_pixel(pos + 0x05, r, g, b);
			set_pixel(pos + 0x06, 0x00, 0x00, 0x00);
			set_pixel(pos + 0x07, 0x00, 0x00, 0x00);
			set_pixel(pos + 0x08, r, g, b);
			break;
		
		case 0x03:
			set_pixel(pos + 0x00, r, g, b);
			set_pixel(pos + 0x01, 0x00, 0x00, 0x00);
			set_pixel(pos + 0x02, 0x00, 0x00, 0x00);
			set_pixel(pos + 0x03, r, g, b);
			set_pixel(pos + 0x04, r, g, b);
			set_pixel(pos + 0x05, 0x00, 0x00, 0x00);
			set_pixel(pos + 0x06, r, g, b);
			set_pixel(pos + 0x07, r, g, b);
			set_pixel(pos + 0x08, 0x00, 0x00, 0x00);
			break;

		case 0x04:	
			set_pixel(pos + 0x00, 0x00, 0x00, 0x00);
			set_pixel(pos + 0x01, 0x00, 0x00, 0x00);
			set_pixel(pos + 0x02, 0x00, 0x00, 0x00);
			set_pixel(pos + 0x03, 0x00, 0x00, 0x00);
			set_pixel(pos + 0x04, r, g, b);
			set_pixel(pos + 0x05, r, g, b);
			set_pixel(pos + 0x06, r, g, b);
			set_pixel(pos + 0x07, r, g, b);
			set_pixel(pos + 0x08, 0x00, 0x00, 0x00);
			break;

		case 0x05:
			set_pixel(pos + 0x00, r, g, b);
			set_pixel(pos + 0x01, r, g, b);		
			set_pixel(pos + 0x02, 0x00, 0x00, 0x00);
			set_pixel(pos + 0x03, r, g, b);
			set_pixel(pos + 0x04, r, g, b);
			set_pixel(pos + 0x05, 0x00, 0x00, 0x00);
			set_pixel(pos + 0x06, 0x00, 0x00, 0x00);
			set_pixel(pos + 0x07, r, g, b);
			set_pixel(pos + 0x08, 0x00, 0x00, 0x00);
			break;

		case 0x06:
			set_pixel(pos + 0x00, 0x00, 0x00, 0x00);
			set_pixel(pos + 0x01, 0x00, 0x00, 0x00);
			set_pixel(pos + 0x02, r, g, b);
			set_pixel(pos + 0x03, r, g, b);
			set_pixel(pos + 0x04, r, g, b);
			set_pixel(pos + 0x05, 0x00, 0x00, 0x00);
			set_pixel(pos + 0x06, r, g, b);
			set_pixel(pos + 0x07, r, g, b);
			set_pixel(pos + 0x08, 0x00, 0x00, 0x00);
			break;

		case 0x07:
			set_pixel(pos + 0x00, r, g, b);			
			set_pixel(pos + 0x01, 0x00, 0x00, 0x00);
			set_pixel(pos + 0x02, 0x00, 0x00, 0x00);
			set_pixel(pos + 0x03, 0x00, 0x00, 0x00);
			set_pixel(pos + 0x04, 0x00, 0x00, 0x00);
			set_pixel(pos + 0x05, r, g, b);
			set_pixel(pos + 0x06, 0x00, 0x00, 0x00);
			set_pixel(pos + 0x07, 0x00, 0x00, 0x00);
			set_pixel(pos + 0x08, r, g, b);
			break;

		case 0x08:
			set_pixel(pos + 0x00, r, g, b);
			set_pixel(pos + 0x01, r, g, b);
			set_pixel(pos + 0x02, r, g, b);
			set_pixel(pos + 0x03, r, g, b);
			set_pixel(pos + 0x04, r, g, b);
			set_pixel(pos + 0x05, r, g, b);
			set_pixel(pos + 0x06, 0x00, 0x00, 0x00);
			set_pixel(pos + 0x07, r, g, b);
			set_pixel(pos + 0x08, 0x00, 0x00, 0x00);
			break;

		case 0x09:
			set_pixel(pos + 0x00, r, g, b);
			set_pixel(pos + 0x01, r, g, b);
			set_pixel(pos + 0x02, 0x00, 0x00, 0x00);
			set_pixel(pos + 0x03, 0x00, 0x00, 0x00);
			set_pixel(pos + 0x04, 0x00, 0x00, 0x00);
			set_pixel(pos + 0x05, r, g, b);
			set_pixel(pos + 0x06, 0x00, 0x00, 0x00);
			set_pixel(pos + 0x07, r, g, b);
			set_pixel(pos + 0x08, r, g, b);
			break;

		case 0x0A:
			set_pixel(pos + 0x00, 0x00, 0x00, 0x00);
			set_pixel(pos + 0x01, 0x00, 0x00, 0x00);
			set_pixel(pos + 0x02, r, g, b);
			set_pixel(pos + 0x03, 0x00, 0x00, 0x00);
			set_pixel(pos + 0x04, r, g, b);
			set_pixel(pos + 0x05, r, g, b);
			set_pixel(pos + 0x06, r, g, b);
			set_pixel(pos + 0x07, r, g, b);
			set_pixel(pos + 0x08, 0x00, 0x00, 0x00);
			break;

		case 0x0B:
			set_pixel(pos + 0x00, 0x00, 0x00, 0x00);
			set_pixel(pos + 0x01, r, g, b);
			set_pixel(pos + 0x02, r, g, b);
			set_pixel(pos + 0x03, r, g, b);
			set_pixel(pos + 0x04, r, g, b);
			set_pixel(pos + 0x05, 0x00, 0x00, 0x00);
			set_pixel(pos + 0x06, 0x00, 0x00, 0x00);
			set_pixel(pos + 0x07, r, g, b);
			set_pixel(pos + 0x08, 0x00, 0x00, 0x00);
			break;
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

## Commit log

2017-01-02 Use LSB of input char to toggle an LED
2017-01-02 Write to neopixel instead of LED pin
2017-01-02 Print '.' and 'x' for acknowledgement
2017-01-02 Complain if no device is found
2024-09-05 Got a good version
    [#9SegmentV2Slant.dxf, #9segmentDisplay-PartShapeBinder.dxf, 9SegmentV2.FCStd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]
2024-09-07 moving files, adding more
    [#9SegmentV2Slant.dxf, #9segmentDisplay-PartShapeBinder.dxf, 9SegmentV2.FCStd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]
2024-09-16 Started Routing
    [#9SegmentV2Slant25x50x4.dxf, 9SegDigit.kicad_sch, pcb9segCounter.kicad_pcb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]
2024-09-18 Making progress, figuring out microcontroller interfacing
    [9SegDigit.kicad_sch, pcb9segCounter.kicad_pcb, pcb9segCounter.kicad_sch]
2024-09-23 Schematic looks good, going to branch to reduce the number of digits from 4 to 2
    [9SegDigit.kicad_sch, pcb9segCounter.kicad_pcb, pcb9segCounter.kicad_sch]
2024-09-23 Added sub-schematic and gitignore
    [uC.kicad_sch]
2024-09-23 reduced to 2 digits, added capacitors
    [9SegDigit.kicad_sch, pcb9segCounter.kicad_pcb, pcb9segCounter.kicad_sch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]
2024-09-25 Edits prior to setting board edge in freecad
    [pcb9segCounter.kicad_pcb]
2024-09-25 good routing, need to add slikscreen details
    [9SegDigit.kicad_sch, pcb9segCounter.kicad_pcb, pcb9segCounter.kicad_sch]
2024-09-26 adding 3d model which was used to generate board outline, commiting before adding i2c pullups
    [3dBoard.FCStd, pcb9segCounter.kicad_pcb, uC.kicad_sch]
2024-09-26 Looks really good, all footprints and implementation check out. Looking to move an LED and adding an additional decap capacitor
    [9SegDigit.kicad_sch, pcb9segCounter.kicad_pcb, pcb9segCounter.kicad_sch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]
2024-09-26 Everything looks good for manufacture
    [9SegDigit.kicad_sch, pcb9segCounter.kicad_pcb, uC.kicad_sch]
2024-09-26 Added website to board, generated gerber which was sent to oshpark for manufacture
    [pcb9segCounter.kicad_pcb]
2024-09-26 Updated details to export BOM
    [9SegDigit.kicad_sch, pcb9segCounter.kicad_sch, pcb9segCounterBOM.csv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]
2024-10-03 edits to BOM and generation of HTML BOM
    [pcb9segCounterBOM.csv]
2024-10-06 Edits to code and generation of the backplate segment separator
    [saoBackSeparator-backPlate.step, saoBackSeparator.FCStd]
2024-10-06 Made edits to PCB file and generated gerbers for manufacture at JLCPCB
    [pcb9segCounter.kicad_pcb]
2024-10-07 Moving and renaming gerber zip files
2024-10-15 Edits to Readme, found error in the schematic and made a note of it, added EEPROM capability to the code.
    [9SegDigit.kicad_sch, pcb9segCounter.kicad_sch, uC.kicad_sch]
2024-10-16 rebase of TinyWire repo authored by Eero af Heurlin <eero.afheurlin@iki.fi> & Sean Voisen <sean@voisen.org>
    rebase executed by "git rebase --root -i"
    Atmel app notes about USI and I2C
    reformat and add a comment about a certain weird bug
    reorg for github
    added func for returning the actual amount of data in the read buffer (and commented out the possibly-all-call-but-probably-bug)
    added orifinal source
    this still fails, I guess I need to actually think about this...
    link to the avr example source
    use 8bits wide integers here, the buffer is 32 bytes by default anyway
    new versions from http://code.google.com/p/tinkercode/source/browse/trunk/automation-framework/i2c/
    normalize newlines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
    [attiny85_i2c_slave.ino]
2024-10-16 successful compilation of i2cTest.cpp
2024-10-17 attempting to have LED debug
2024-10-18 successful compile, upload, and operation of board using the updated of Makefile
2024-10-20 code compiles and standard button use works
2024-10-20 Compiles an uploads, need to work on I2C usage
2024-10-21 progresss on I2C
2024-10-22 Sent I2C data is successfully displayed, also successful interpretation of number of bytes in message
2024-10-22 i2c number display works, one didgit color set works, two digit color set works. Weirdly starts on the second index of the colors array.
2024-10-22 Everything works well except for I2C setting data and reading back data over I2C
2024-10-22 Implemented reading and writing to EEPROM over I2C
2024-10-22 Added comments and update README, need to investigate why clock and LED seem to be on the same pin
2024-10-22 Looks like the clocking issue was due to the PCB being connected to the AVRISP MKII. Made a minor change to how data is written to memory.
    [mainDigit.cpp]
2024-10-24 Found the error, forgot a break.
    [saoBackSeparator.FCStd]
2024-10-25 Doing lots of cleanup
    [#9SegmentV2Slant.dxf, #9SegmentV2Slant25x50x4.dxf, #9segmentDisplay-PartShapeBinder.dxf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]
2024-10-26 Good test on SN0 I am able to drive the LEDs using the BusPirate, still need to figure out why SN1 drives all LEDs to white when powering up. I am able to drive the LEDs of SN1 when the AVR pin is hi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
2024-10-26 Updated Makefile to include fuse setting parameters
2024-10-28 Added assembly instructions to schematic, generated PDFs, Updated README, Upped LED brightness
2025-10-31 update fuse values to reflect change for lower brownout voltage
